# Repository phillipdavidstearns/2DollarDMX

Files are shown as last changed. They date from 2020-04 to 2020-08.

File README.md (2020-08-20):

# 2DollarDMX

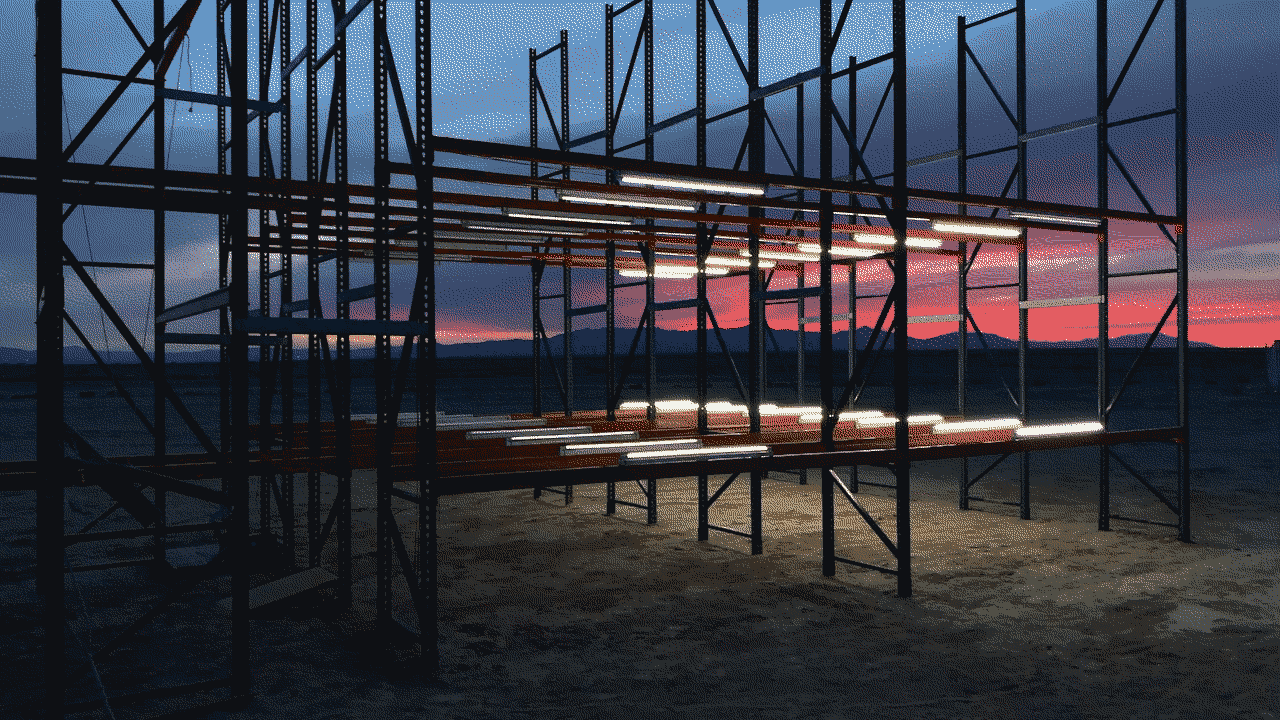
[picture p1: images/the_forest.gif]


An expandable, open-source platform for controlling arrays of Solid State Relays from [Arduino](https://www.arduino.cc/) and [Raspberry Pi](https://www.raspberrypi.org/) with the [CD4094](https://www.alldatasheet.com/datasheet-pdf/pdf/26896/TI/CD4094.html). At the time, it seemed like a cheap alternative to buying a proper [DMX system](https://en.wikipedia.org/wiki/DMX512).

## System Overview

* The 2DollarDMX system allows for the control of binary, on-off AC powered devices (e.g. lights, fans, blenders, TVs, etc...).
* This is accomplished by switching 120/240VAC using solid state relays.
* Relays are chosen based on application but generally are designed to handle 25A loads and controlled by 3.3V-5V pulses.
* Control signals are generated by user-customizable software and low-cost hardware platforms such as Arduino and Raspberry Pi.
* The CD4094, an 8-bit latched shift register from the CMOS 4000 logic family IC, is used to extend the number of controllable devices.
* Either and Arduino of Raspberry Pi control the CD4094 using a mere 4 pins. It's possible for multiple CD4094 ICs to be daisy chained to expand the number of controllable channels.

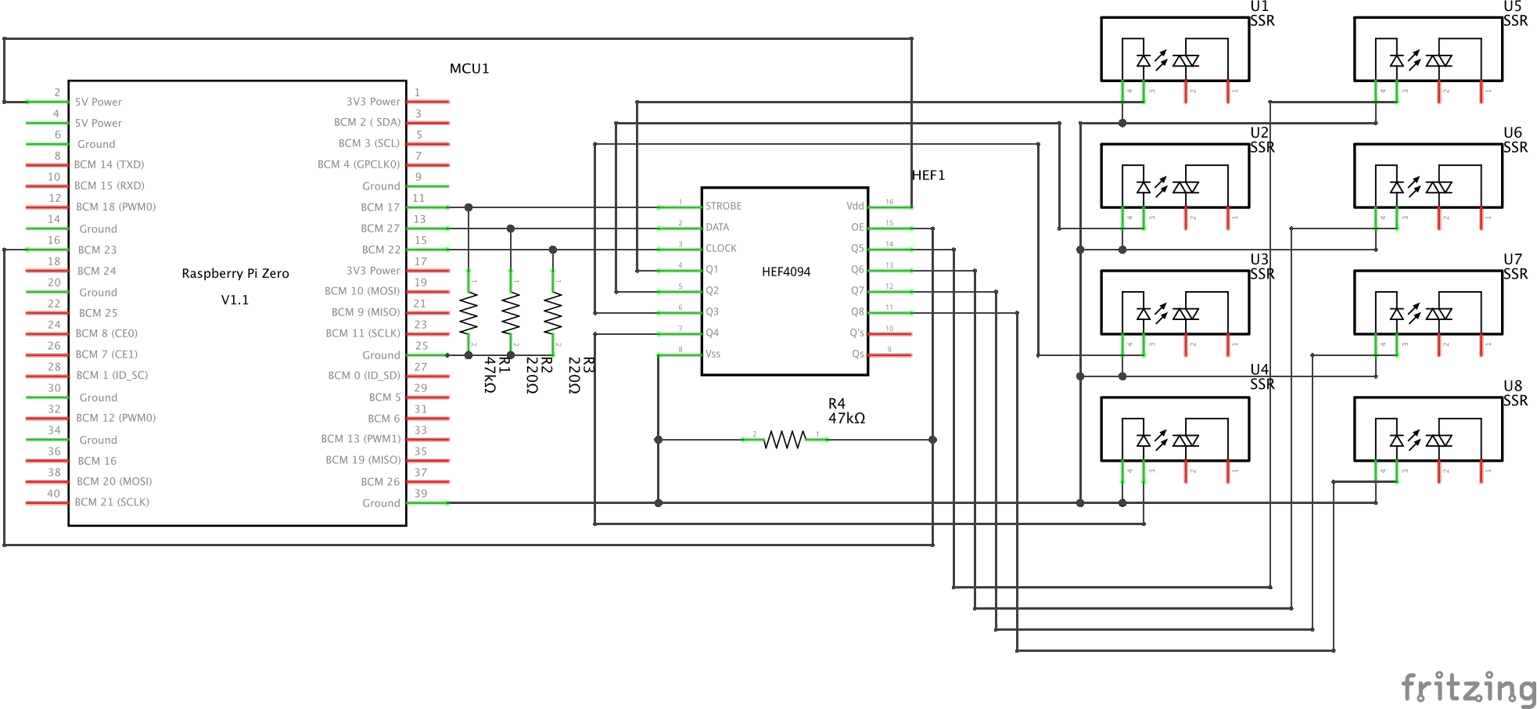
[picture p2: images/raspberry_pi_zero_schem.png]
<br>
A schematic example illustrating the connections between a Raspberry Pi Zero, CD4094 shift register, and an array of Solid State Relays (SSRs).

### Hardware:

#### Shift Registers

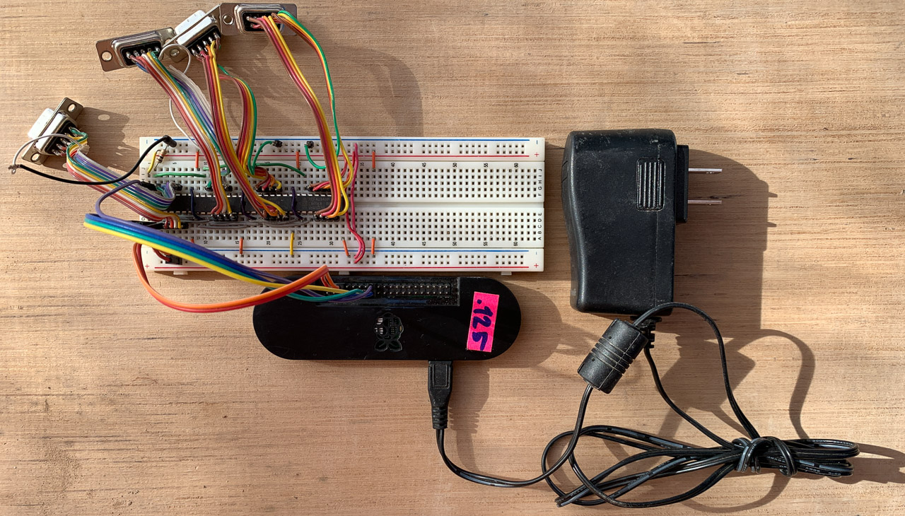
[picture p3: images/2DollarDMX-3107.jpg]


Raspberry Pi Zero W Connected to a series of 4 daisy chained CD4094 ICs on a breadboard:

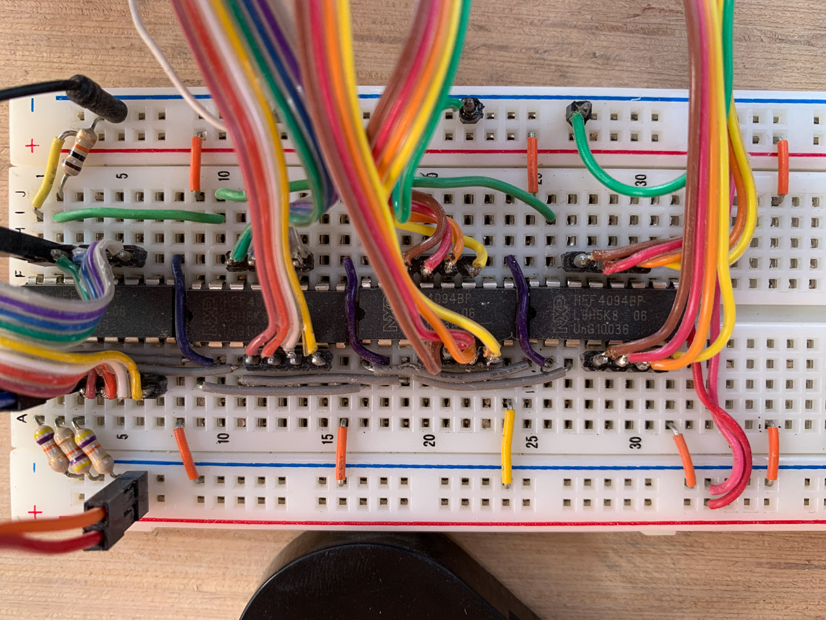
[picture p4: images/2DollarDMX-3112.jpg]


#### Solid State Relays

The Solid State Relays are housed in a gutted and repurposed 8 outlet DJ power distribution box that was sold by Guitar Center for $35.

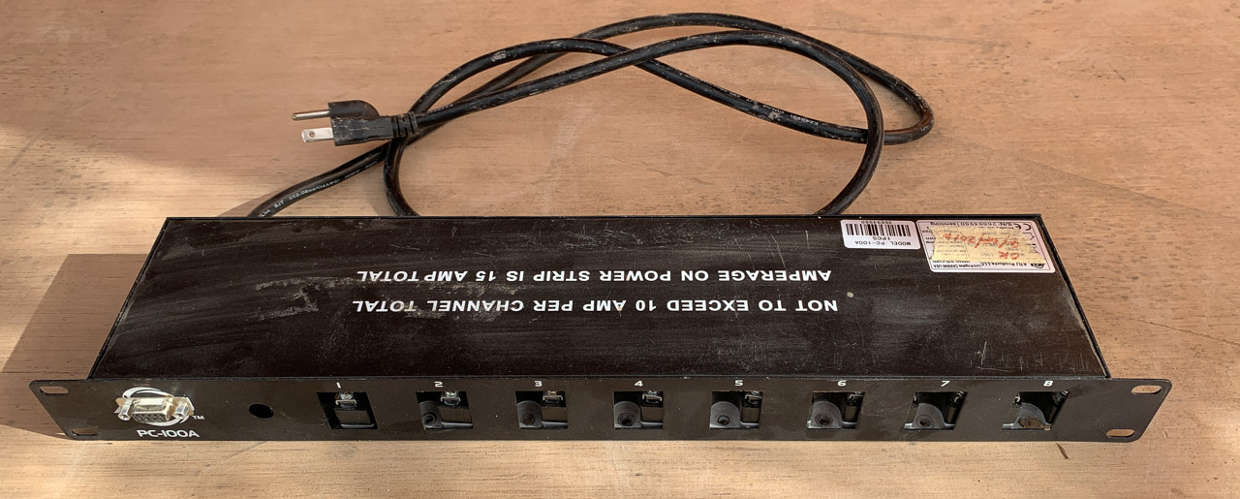
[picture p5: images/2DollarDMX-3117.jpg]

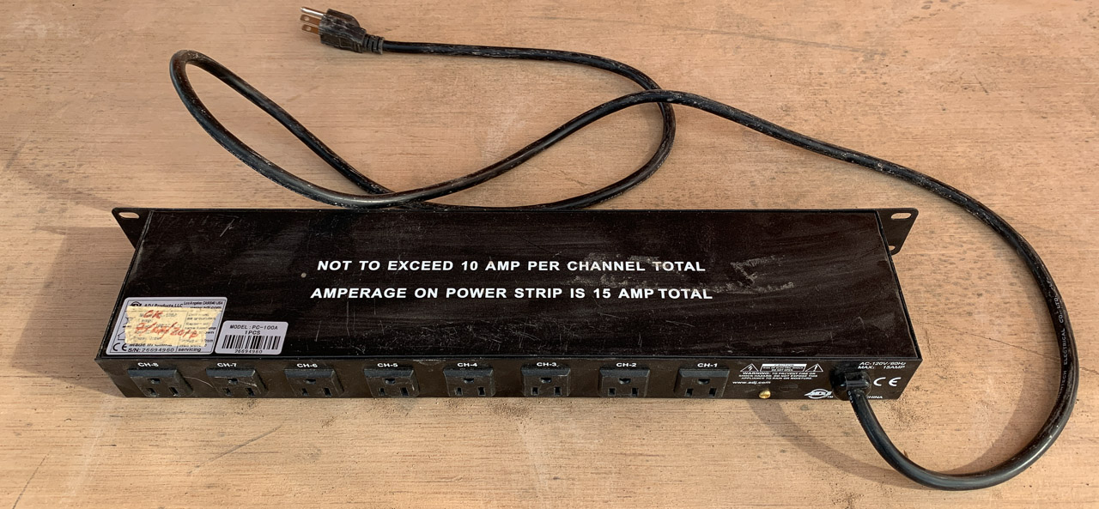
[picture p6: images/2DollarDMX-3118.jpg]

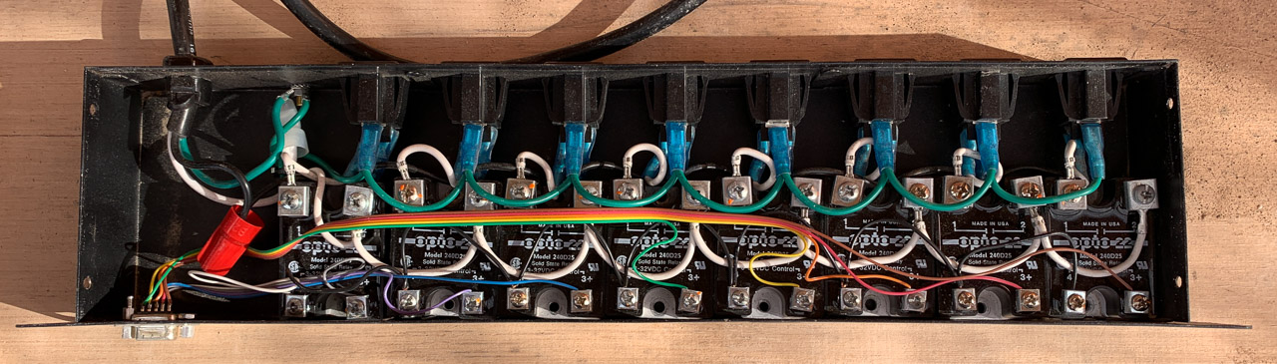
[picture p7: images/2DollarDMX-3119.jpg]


#### Solid State Relay Connections

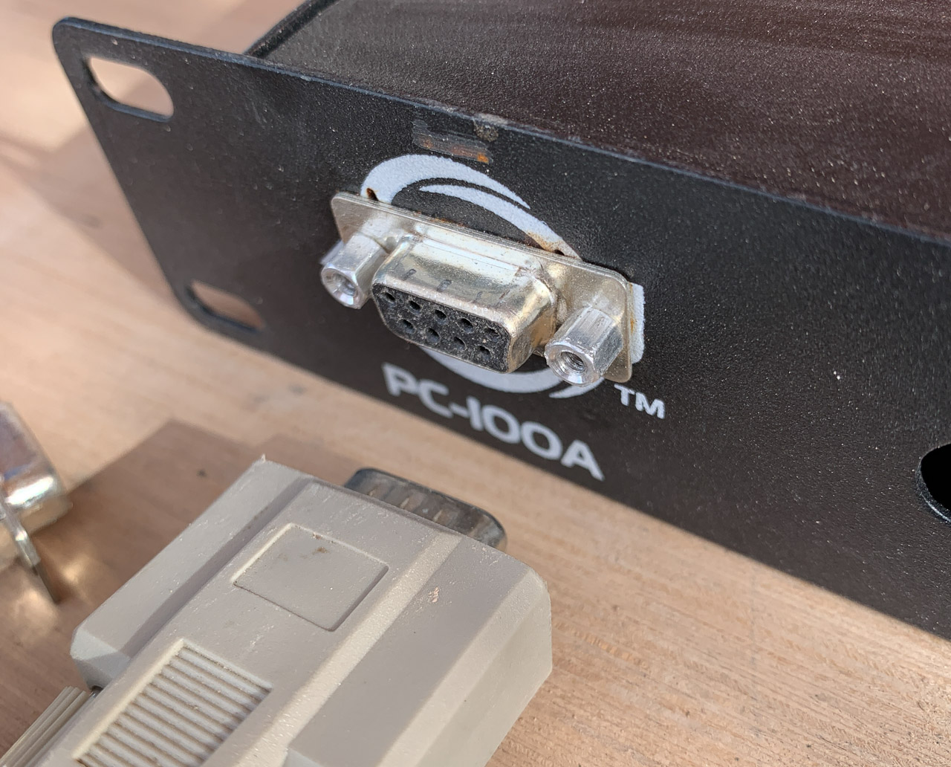
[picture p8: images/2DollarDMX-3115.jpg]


* The CD4094s are wired to DB9 connectors typically used for serial connections.
* Serial pins are mapped as follows:

```
Pin Name		CD4094  	DB9
--------		------  	---
Q1			4		1
Q2			5		2
Q3			6		3
Q4			7		4
Q5			14		5
Q6			13		6
Q7			12		7
Q8			11		8
Ground			8		9

``` 
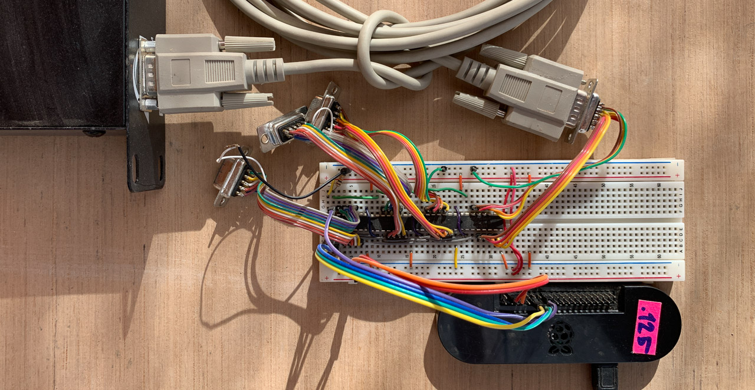
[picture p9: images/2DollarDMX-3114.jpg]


### Software

The goal of the software is:

1. read in data over a given protocol
1. translate it to control signals for the CD4094 shift registers

Currently, the encoding is 1:1 in such a way that each byte represents the desired state of the shift register output pins:

```
In the Forest installation, 32 channels were encoded in 4 bytes as follows.

Byte 1 = lights 1-8
-------------------
00000000

Byte 2 = lights 9-16
-------------------
00000000

Byte 3 = lights 17-24
-------------------
00000000

Byte 4 = lights 25-32
-------------------
00000000
```

**Raspberry Pi**

The Raspberry Pi is running Python code that translates incoming data streams (currently TCP/IP payloads) into control signals for the CD4094 via a custom [rpi-cd4094](https://github.com/phillipdavidstearns/rpi-cd4094.git) package, a convenient wrapper of the standard [RPi.GPIO](https://pypi.org/project/RPi.GPIO/) package used for reading from and writing to the Raspberry Pi's General Purpose Input/Output pins.

Any application that can open a raw TCP/IP connection can control the lights.

**Arduino**

The Arduino runs a sketch that accepts serial over the USB connection and translates 4 bytes into the signals to control 4 CD4094 shift registers for a total of 32 channels.

## Installation (OSX)

1. Create a project directory: `mkdir ~/my_project`
1. Change to that directory: `cd ~/my_project`
1. Clone this repository: `git clone https://github.com/phillipdavidstearns/2DollarDMX.git`
1. To use the Processing controller, download and install [Processing 3](https://processing.org/download/).

### Raspberry Pi

1. `ssh` into your Raspberry Pi
1. Clone rpi-cd4094: `git clone https://github.com/phillipdavidstearns/rpi-cd4094.git`
1. Install rpi-cd4094: `cd rpi-cd4094; sudo python3 setup.py install`
1. Follow the directions to install the_forest at: [https://github.com/phillipdavidstearns/the_forest](https://github.com/phillipdavidstearns/the_forest)

### Arduino

1. Download and Install the Arduino IDE
1. Install the TimerOne library: `cd ~/Documents/Arduino/libraries; git clone https://github.com/PaulStoffregen/TimerOne`
1. Flash your Arduino with the sketch located at `2DollarDMX/examples/arduino/serial_control/serial_control.ino`

## Connections

**Raspberry Pi**

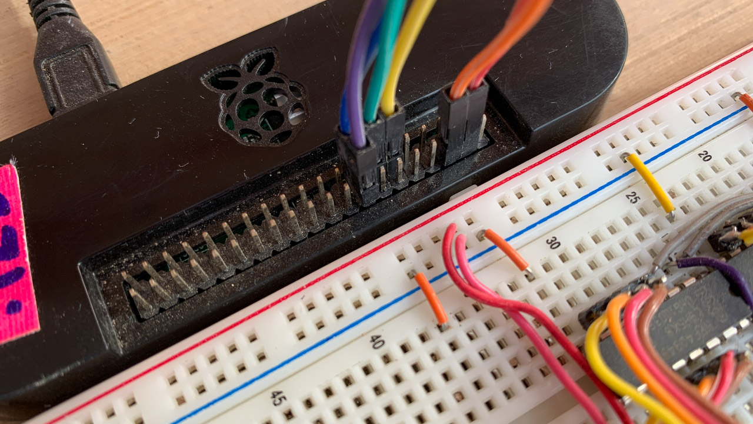
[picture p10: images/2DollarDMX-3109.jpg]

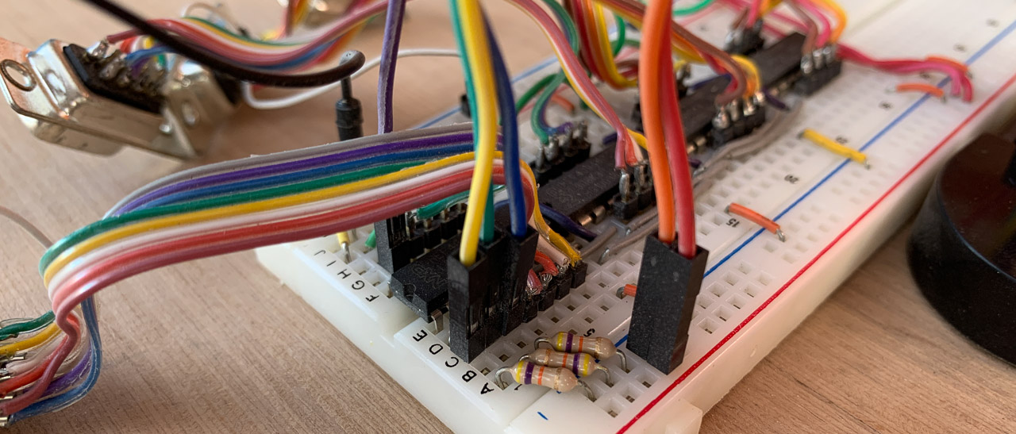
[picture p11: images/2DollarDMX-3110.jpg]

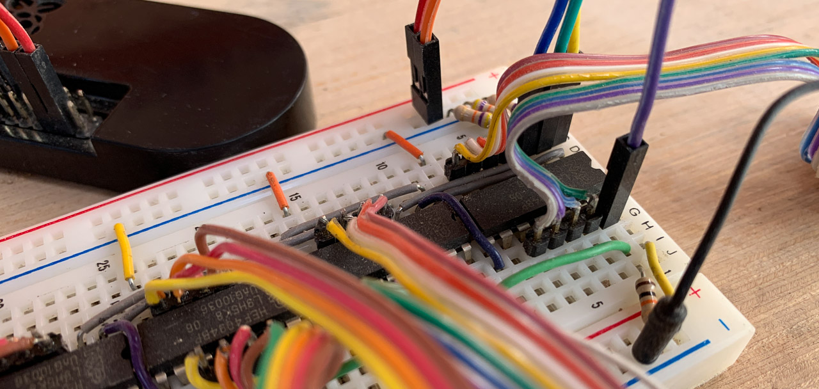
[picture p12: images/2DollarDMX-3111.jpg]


**Arduino**

*nothing here yet, but refer to the Arduino sketch for hard coded pins*

## Operation

**Raspberry Pi**

See [the_forest](https://github.com/phillipdavidstearns/the_forest) repo for examples of how this hardware setup was used to:

* Visualize network broadcast traffic in real-time
* Allow for local network control over TCP/IP

Once [the_forest](https://github.com/phillipdavidstearns/the_forest) is installed on the Raspberry Pi:

1. Start `the_forest.service`: `sudo systemctl start the_forest.service`
1. Run the `controller.pde` Processing sketch in `.examples/processing/controller/` to control the lights. 

**Arduino**

*come back later*

## Max channels?

#### Arduino

Operations per bit (and cost in clock cycles) using port manipulation. Timings based on [this post](https://timodenk.com/blog/port-manipulation-and-arduino-digitalwrite-performance/).

**Shifting Data into the Register:**

* set data pin (2 clock cycles)
* set clock pin HIGH (2 clock cycles)
* set clock pin LOW (2 clock cycles)
* 6 cycles total per channel

**Updating Register (strobe the latch)**

* set strobe pin HIGH (2 clock cycles)
* set strobe pin LOW (2 clock cycles)
* 4 cycles to update

**Theoretical Max Number of Channels**

* Cycles per frame @ 30 fps = 16Mhz / 30fps = 533,333 cycles per frame
* 533,333 cycles per frame - 4 cycles to strobe = 533,329 cycles
* 533,329 cycles / 6 cycles per channel = 88,888 channels

#### Raspberry Pi

Although the processor is much faster on the Raspberry Pi that that of the Arduino, running the GPIO at large percentage of the available CPU speed will consume massive amounts of energy. To look at the problem from a different angle, you could calculate the minimum required clock speed for a given number of channels.

* number of channels x cycles per channel + 4 x number of updates per second = minimum required clock rate
* 2048 elements per frame @ 30 frames per second would require a clock rate of 368760Hz (2048 x 6 + 4 x 30)

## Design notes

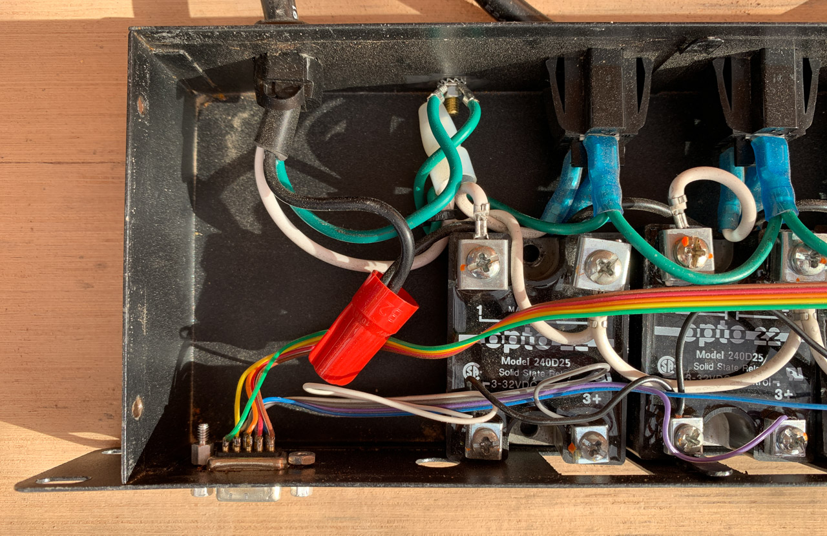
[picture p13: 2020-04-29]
images/2DollarDMX-3121.jpg

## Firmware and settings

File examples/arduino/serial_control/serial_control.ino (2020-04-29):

/*
   32 Light control system code for Arduino Nano

   Reads a 4 byte (32bit) "command" from the serial port and outputs it to a
   32 bit serial to parallel array made from daisy chained CD4094 CMOS shift registers

   Note that modifying this code for other Arduino platforms will require changin
   pin numbers and IO/PORT. Here pins 10, 11, 12, are Strobe, Data, and Clock rsp.
   IO is controlled via PORTB on Nano and Uno/Deumillanova boards.

*/

//Timer1 used maintain a steady refresh rate of the lamps.
#include <TimerOne.h>

//display register control pins
#define ENABLE 9
#define STROBE 10
#define DATA 11
#define CLK 12

byte lights[4];
volatile unsigned long int count;

//////////////////////////////////////////////////////////////////////////////

void setup() {
  PORTB = B00000000; // disable shiftregister output
  Timer1.initialize(1e6 / 30); // period in micro seconds (1x10^6 / frames per second)
  Timer1.attachInterrupt(callback);

  //note: use setPeriod(period) to adjust the frequency of stuff

  pinMode(CLK, OUTPUT);
  pinMode(DATA, OUTPUT);
  pinMode(STROBE, OUTPUT);
  pinMode(ENABLE, OUTPUT);
  Serial.begin(115200);
  PORTB = B00000010; // enable shiftregister output
}

//////////////////////////////////////////////////////////////////////////////

void loop() {
  serial();
}

void callback() {
  updateRegisters();
}

void serial() {
  if (Serial.available() >= 5) { // start reading when the buffer has enough data
    if (Serial.read() == 0xA0) { // 0xA0 is an arbitrary sync bit being transmitted by the processing patch before every transmission 
      for (int i = 0 ; i < 4; i++) {
        lights[i] = Serial.read();
      }
    }
  }
}

void updateRegisters() {

  // B00000000
  //     ^^^^
  //     ||||
  // pin12||| connected to the clock pin of the 4094 array
  //  pin11|| connected to the data pin of the 4094 array
  //   pin10| connected to the strobe pin of the 4094 array
  //    pin09 connected to the enable pin of the 4094 array  
 
  //load data into 4094 shift registers MSB to LSB (BACKWARDS ;)
  for (int i = 3 ; i >= 0 ; i--) { //run through the bytes
   for(int j = 7 ; j >= 0 ; j--){ //run through each bit
    PORTB = ((lights[i] >> j) & 1) << 3; //change the state of the data pin
    PORTB |= B00010010; //pulse clock pin
    PORTB = B00000010; // return clock and data to 0
   }
  }
  //pulse strobe to update 4094 shift registers
  PORTB = B00000110;
  PORTB = B00000010;
}

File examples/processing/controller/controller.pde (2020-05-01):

/*
 
 2DollarDMX example GUI Control Interface
 
 by Phillip David Stearns 2018
 
 Communicates to a Arduino via serial, Raspberry Pi via TCP/IP
 Arduino Code:
 Raspberry Pi Code:
 
 
 
 */

import processing.serial.*;
import processing.net.*;

//serial communication
Serial arduinoPort;
// networking stuff
Client c;

String IP_ADDR = "10.79.10.125";
int PORT = 31337;

boolean editMode;
boolean demoMode;
boolean manual;
int connMode=1; // connection method 0 = serial, 1 = TCP/IP

//variables associated with Light
ArrayList <Light> lights;
int lightCount;
int lightsMax = 32;
boolean allOn;
boolean random;
boolean caOn;
boolean inverted;
boolean lfsrOn;
int serialPort = 1; // *** set this to the device you want to send serial data to! ***

//variables associated with Group
ArrayList <Group> groups;
int groupCount;
int groupsMax = 6;
boolean[] group; //holds logic for toggling groups on and off
String[] groupNames = {"KEYS", "DRUMS", "VOCALS", "GUITAR", "BASS"};

ArrayList <Ring> rings;
ArrayList <Line> lines;

CA ca;
LFSR lfsr;

color bgcolor;

//variables for calculating and drawing the grid
float stageWidth =24; // in feet
float stageDepth=12; // in feet
float wallHeight=6; // in feet
float gridWidth; // in pixels
float gridHeight; // in pixels
float gridSize; // in pixels
float padding = 25; // in pixels
int heavy = 4;
int medium = 2;
int light = 1;
float gridXstart;
float gridXend;
float gridYstart;
float gridYend;
float textX;
float columnLabelY;
float rowLabelX;

/////////////////////////////////SETUP///////////////////////////////

void setup() {
  //size(800, 600);
  fullScreen();
  frameRate(30);

  println("[+] Initializing network client...");

  establishConnection();

  computeGrid();
  drawGrid();

  editMode=false; //0 = edit, 1 = perform
  demoMode=false;
  manual=false;

  lights = new ArrayList<Light>();
  lightCount=0;
  allOn = false;
  inverted = false;
  random = false;
  caOn = false;
  lfsrOn = false;

  groups = new ArrayList<Group>();
  groupCount=0;
  group = new boolean[groupsMax];

  rings = new ArrayList<Ring>();
  lines = new ArrayList<Line>();

  ca = new CA();
  lfsr = new LFSR();

  loadSettings();
}

/////////////////////////////////MAIN LOOP///////////////////////////////

void draw() {

  if (editMode) {
    bgcolor = 63;
  } else if (inverted) {
    bgcolor = 127;
  } else {
    bgcolor = 0;
  }

  background(bgcolor);

  drawGrid();

  if (!editMode) {
    updateRings();
    updateLines();
    if (caOn) ca.update();
    if (lfsrOn) lfsr.update();
  }
  //updateGroups();
  updateLights();
  sendData(packLights());
}

/////////////////////////////////FUNCTIONS///////////////////////////////

void establishConnection() {
  switch(connMode) {
  case 0:
    printArray(Serial.list()); // List all the available serial ports:
    try {
      arduinoPort = new Serial(this, Serial.list()[serialPort], 115200); // Open the port you are using at the rate you want
    } 
    catch(Exception e) {
      println(e);
      exit();
    }
    break;
  case 1:
    try {
      c = new Client(this, IP_ADDR, PORT); // Replace with your server’s IP and port
    } 
    catch( Exception e) {
      println(e);
    }
    if (!c.active()) {
      println("Failed to connect to remote server. Check IP and whether the service is listening.");
      exit();
    }
    break;
  default:
    break;
  }
}

void computeGrid() {
  if (width/stageWidth < height/(stageDepth+wallHeight)) {
    gridSize = (width-(2*padding))/stageWidth;
  } else {
    gridSize = (height-(2*padding))/(stageDepth+wallHeight);
  }
  gridWidth = gridSize*stageWidth;
  gridHeight = gridSize*(stageDepth+wallHeight);
  gridXstart = (width - gridWidth)/2;
  gridYstart = (height - gridHeight)/2;
  columnLabelY=height-gridYstart+(gridSize/4);
  rowLabelX=gridXstart-(gridSize/4);
  gridYend = height-gridYstart;
  gridXend = width-gridXstart;
}

void drawGrid() {

  //Grid colors
  if (editMode) {
    fill(255);  
    stroke(255);
  } else if (inverted) {
    fill(63);
    stroke(63);
  } else {
    fill(127);
    stroke(127);
  }

  textAlign(CENTER, CENTER);

  //draw vertical lines
  for (int x = 0; x <= stageWidth; x++) {
    //set line weight
    if (x==0 || x == stageWidth) {
      strokeWeight(heavy);
    } else if (x % 2 == 0) {
      strokeWeight(medium);
    } else {
      strokeWeight(light);
    }
    //label grid
    float columnLabelX=gridXstart+(gridSize*x)+(gridSize/2);
    if (x < stageWidth) text(x+1, columnLabelX, columnLabelY);
    float boxX = gridXstart+(gridSize*x);
    line(boxX, gridYstart, boxX, gridYend);
    strokeWeight(0);
    line(boxX, 0, boxX, height);
  }

  //draw horizontal lines
  for (int y = 0; y <= wallHeight+stageDepth; y++) {
    //set line weight
    if (y==wallHeight || y==0 || y == wallHeight+stageDepth) {
      strokeWeight(heavy);
    } else if (y % 2 == 0) {
      strokeWeight(medium);
    } else {  
      strokeWeight(light);
    }
    //label grid
    float rowLabelY = gridYstart+(gridSize*y)+(gridSize/2);
    if (y < stageDepth+wallHeight) text(y+1, rowLabelX, rowLabelY);
    float boxY = gridYstart+(gridSize*y);
    line(gridXstart, boxY, gridXend, boxY);
    strokeWeight(0);
    line(0, boxY, width, boxY);
  }
}

void updateRings() {
  for (int i = rings.size() - 1; i >= 0; i--) {
    Ring ring = rings.get(i);
    if (ring.isDone()) {
      rings.remove(i);
    } else {
      ring.update();
    }
  }
}

void updateLines() {
  for (int i = lines.size() - 1; i >= 0; i--) {
    Line line = lines.get(i);
    if (line.isDone()) {
      lines.remove(i);
    } else {
      line.update();
    }
  }
}

void updateLights() {
  for (Light light : lights) {
    light.update();
  }
}

void updateGroups() {
  for (Group group : groups) {
    group.update();
  }
}

long packLights() {
  long packed=0;
  for (int i = lights.size()-1; i >=0; i--) {
    Light light = lights.get(i);
    packed |= int(light.isOn()) << i;
  }
  return packed;
}

void sendData(long _output) {
  byte data = 0;
  byte payload[] = new byte[4];
  for (int i = 0; i < 4; i++) {
    data = byte((_output >> (i*8)) & 0xFF);
    payload[i]=data;
  }
  switch(connMode) {
  case 0:
    arduinoPort.write(0xA0); // send sync byte, Arduino is looking for 0xA0
    arduinoPort.write(payload);
    break;
  case 1:
    try {
      c.write(payload);
    } 
    catch(Exception e) {
      exit();
    }
    break;
  }
}

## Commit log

2020-04-29 shuffling files, adding pretty pictures
    [groups 2.csv, groups.csv, lights 2.csv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]
2020-08-20 Update README.md
    Correct tab spacing for 4094 to DB9 wiring to look nice on github ;)
